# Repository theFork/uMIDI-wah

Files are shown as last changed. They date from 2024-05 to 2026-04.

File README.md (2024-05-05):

# uMIDI-wah

An optical guitar wah circuit based on the weeping demon circuit

* Uses [uMIDI](https://github.com/theFork/uMIDI) for control, MIDI and USB communication
* Optical wah control using a PWM

## uMIDI attachment
In order to be able to mount a uMIDI on top of the board, the three uMIDI GPIO connectors (boxed headers) have to be placed on its bottom side. Also, a male pin header row (1x10 pins, 2.54mm) has to be soldered to the MIDI and power section of the uMIDI module (also bottom side).

Another option would be to attach the uMIDI below the wah PCBA. In this case, the connectors have to side on the top side of the PCB.

In both cases, female headers are required for the wah PCBA:

* 3x Female header 2x5 pins, 2.54mm (i.e. TE 215307-5)
* 1x Female header 1x10 pins, 2.54mm (i.e. TE 1-215297-0)

## EDA
* Requires KiCad 8.x.x

## Ressources
Many of this is based on the work of Chet Gnegy: https://ccrma.stanford.edu/~chet/projects/weepingdemon.html

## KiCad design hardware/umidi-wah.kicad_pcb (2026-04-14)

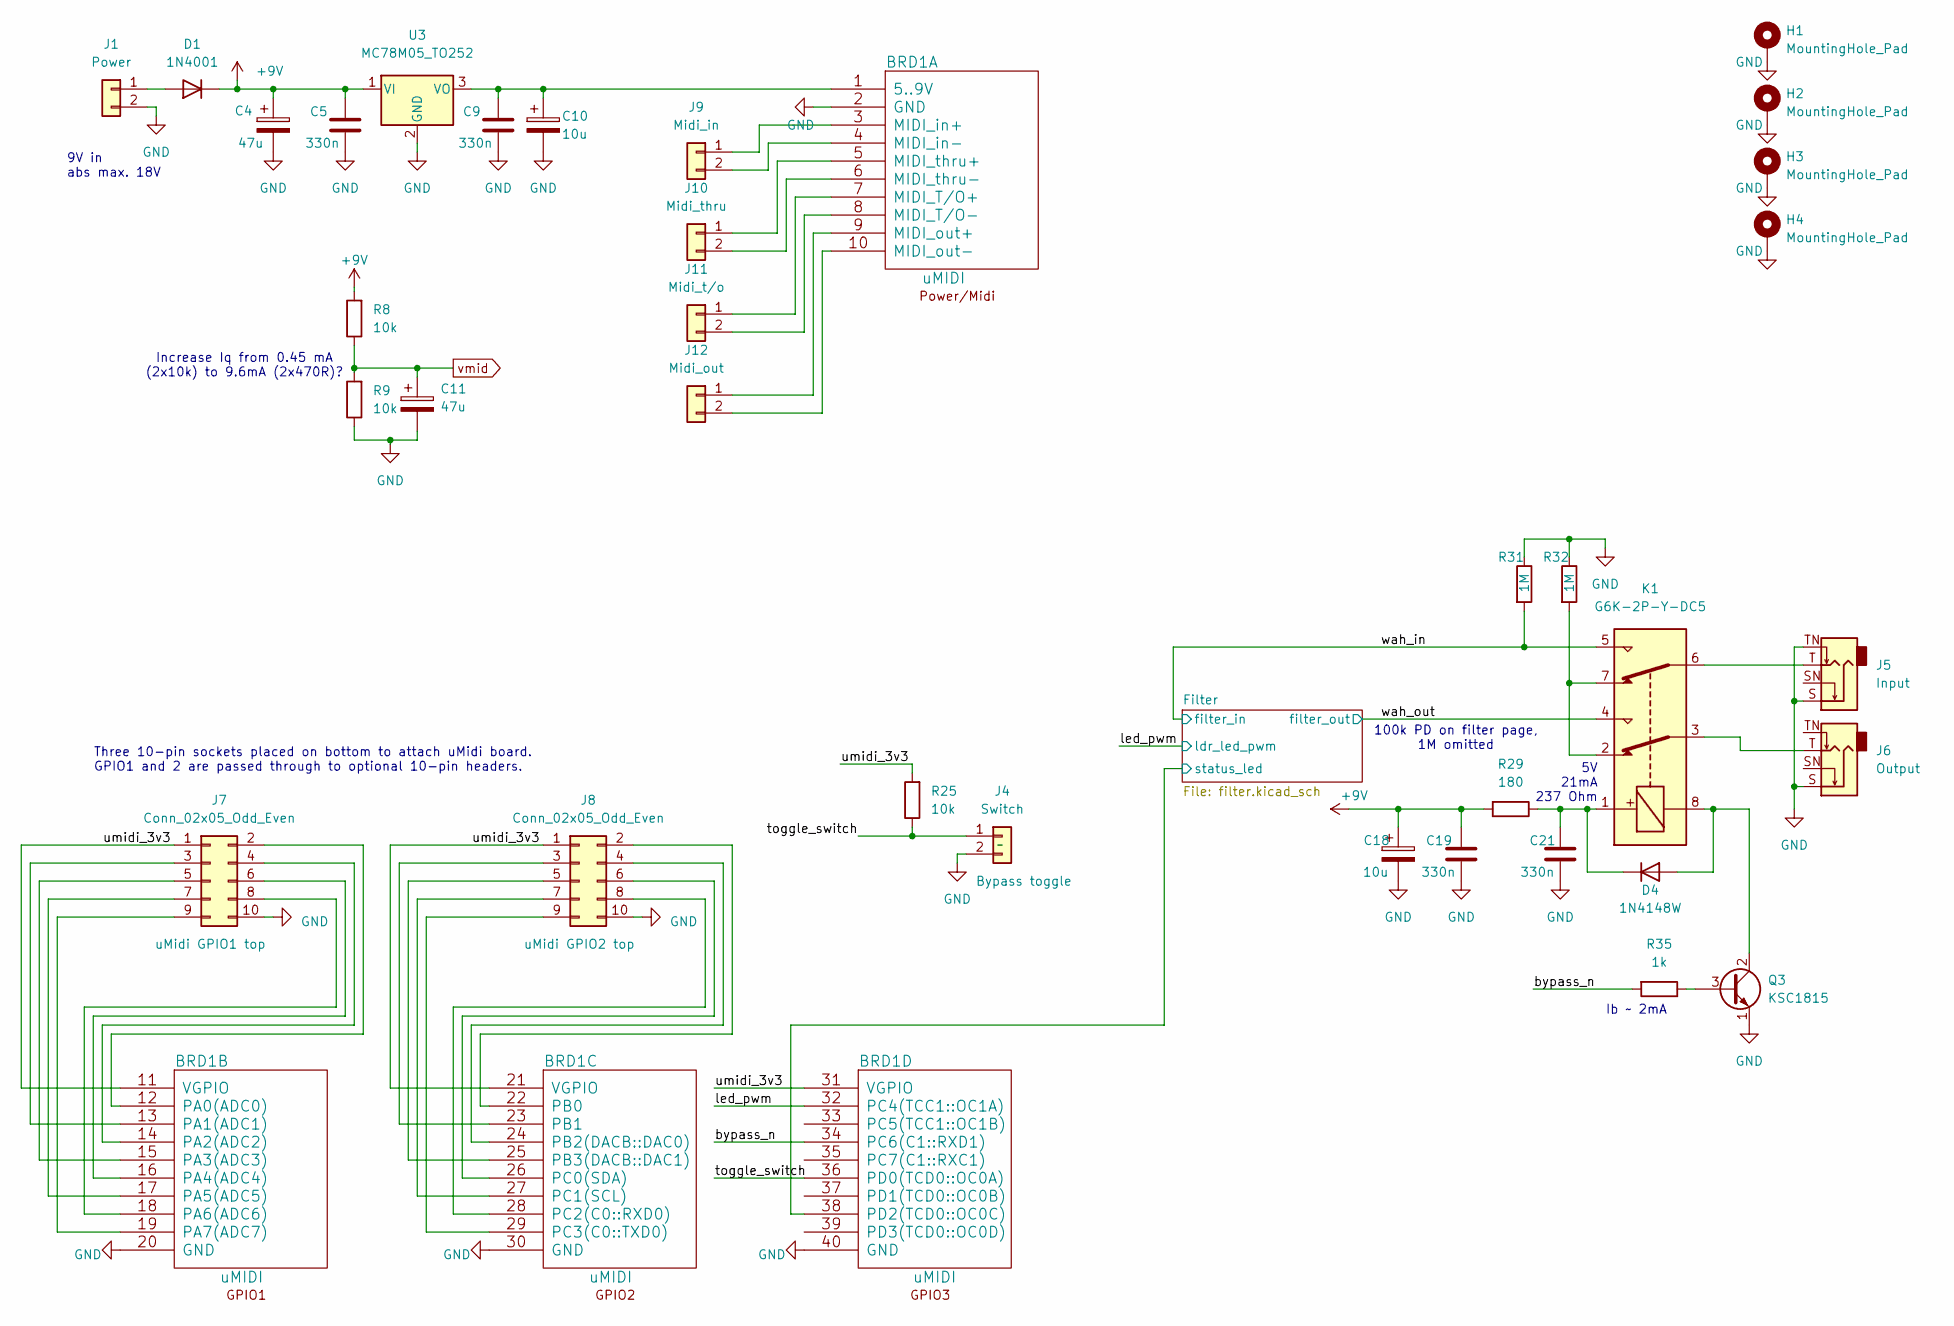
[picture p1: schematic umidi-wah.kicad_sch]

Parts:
BRD1: uMIDI; uMIDI_faceup
C4, C11: 47u; C_1206_3216Metric_Pad1.33x1.80mm_HandSolder
C5, C9, C19, C21: 330n; C_0805_2012Metric_Pad1.18x1.45mm_HandSolder
C10, C18: 10u; C_1206_3216Metric_Pad1.33x1.80mm_HandSolder
D1: 1N4001; D_DO-41_SOD81_P10.16mm_Horizontal
D4: 1N4148W; D_SOD-123
H1, H2, H3, H4: MountingHole_Pad; MountingHole_3.2mm_M3_Pad
J1: Power; SolderWire-1sqmm_1x02_P5.4mm_D1.4mm_OD2.7mm
J4: Switch; SolderWire-1sqmm_1x02_P5.4mm_D1.4mm_OD2.7mm
J5: Input; Jack_6.35mm_Neutrik_NMJ4HCD2_Horizontal
J6: Output; Jack_6.35mm_Neutrik_NMJ4HCD2_Horizontal
J7, J8: Conn_02x05_Odd_Even; IDC-Header_2x05_P2.54mm_Vertical
J9: Midi_in; SolderWire-1sqmm_1x02_P5.4mm_D1.4mm_OD2.7mm
J10: Midi_thru; SolderWire-1sqmm_1x02_P5.4mm_D1.4mm_OD2.7mm
J11: Midi_t/o; SolderWire-1sqmm_1x02_P5.4mm_D1.4mm_OD2.7mm
J12: Midi_out; SolderWire-1sqmm_1x02_P5.4mm_D1.4mm_OD2.7mm
K1: G6K-2P-Y-DC5; Relay_DPDT_Omron_G6K-2P-Y; Manufacturer Part Number G6K-2P-Y-DC5
Q3: KSC1815; TO-92; Manufacturer Part Number KSC1815
R8, R9, R25: 10k; R_0805_2012Metric_Pad1.20x1.40mm_HandSolder
R29: 180; R_0805_2012Metric_Pad1.20x1.40mm_HandSolder
R31, R32: 1M; R_0805_2012Metric_Pad1.20x1.40mm_HandSolder
R35: 1k; R_0805_2012Metric_Pad1.20x1.40mm_HandSolder
U3: MC78M05_TO252; TO-252-2; Manufacturer Part Number MC78M05CD

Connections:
+9V: C4.1, C5.1, C18.1, C19.1, D1.1 (K), R8.2, R29.2, U3.1 (VI); also elsewhere on the board
/Filter/status_led: BRD1.38 (PD2(TCD0::OC0C)); also elsewhere on the board
/bypass_n: BRD1.34 (PC6(C1::RXD1)), R35.2
/led_pwm: BRD1.32 (PC4(TCC1::OC1A)); also elsewhere on the board
/toggle_switch: BRD1.36 (PD0(TCD0::OC0A)), J4.1, R25.1
/umidi_3v3: BRD1.11 (VGPIO), BRD1.21 (VGPIO), BRD1.31 (VGPIO), J7.1, J8.1, R25.2
/wah_in: K1.5, R31.2; also elsewhere on the board
/wah_out: K1.4; also elsewhere on the board
GND: BRD1.2 (GND), BRD1.20 (GND), BRD1.30 (GND), BRD1.40 (GND), C4.2, C5.2, C9.2, C10.2, C11.2, C18.2, C19.2, C21.2, H1.1, H2.1, H3.1, H4.1, J1.2, J4.2, J5.S, J5.TN, J6.S, J7.10, J8.10, Q3.1 (E), R9.1, R31.1, R32.1, U3.2 (GND); also elsewhere on the board
unnamed: BRD1.1 (5..9V), C9.1, C10.1, U3.3 (VO)
unnamed: BRD1.7 (MIDI_T/O+), J11.1
unnamed: BRD1.8 (MIDI_T/O-), J11.2
unnamed: BRD1.3 (MIDI_in+), J9.1
unnamed: BRD1.4 (MIDI_in-), J9.2
unnamed: BRD1.9 (MIDI_out+), J12.1
unnamed: BRD1.10 (MIDI_out-), J12.2
unnamed: BRD1.5 (MIDI_thru+), J10.1
unnamed: BRD1.6 (MIDI_thru-), J10.2
unnamed: BRD1.12 (PA0(ADC0)), J7.2
unnamed: BRD1.13 (PA1(ADC1)), J7.3
unnamed: BRD1.14 (PA2(ADC2)), J7.4
unnamed: BRD1.15 (PA3(ADC3)), J7.5
unnamed: BRD1.16 (PA4(ADC4)), J7.6
unnamed: BRD1.17 (PA5(ADC5)), J7.7
unnamed: BRD1.18 (PA6(ADC6)), J7.8
unnamed: BRD1.19 (PA7(ADC7)), J7.9
unnamed: BRD1.22 (PB0), J8.2
unnamed: BRD1.23 (PB1), J8.3
unnamed: BRD1.24 (PB2(DACB::DAC0)), J8.4
unnamed: BRD1.25 (PB3(DACB::DAC1)), J8.5
unnamed: BRD1.26 (PC0(SDA)), J8.6
unnamed: BRD1.27 (PC1(SCL)), J8.7
unnamed: BRD1.28 (PC2(C0::RXD0)), J8.8
unnamed: BRD1.29 (PC3(C0::TXD0)), J8.9
unnamed: D1.2 (A), J1.1
unnamed: D4.2 (A), K1.8, Q3.2 (C)
unnamed: C21.1, D4.1 (K), K1.1, R29.1
unnamed: J5.T, K1.6
unnamed: J6.T, K1.3
unnamed: K1.2, K1.7, R32.2
unnamed: Q3.3 (B), R35.1
vmid: C11.1, R8.1, R9.2; also elsewhere on the board

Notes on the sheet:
Increase Iq from 0.45 mA (2x10k) to 9.6mA (2x470R)?
9V in abs max. 18V
Ib ~ 2mA
Three 10-pin sockets placed on bottom to attach uMidi board. GPIO1 and 2 are passed through to optional 10-pin headers.
100k PD on filter page, 1M omitted
5V 21mA 237 Ohm

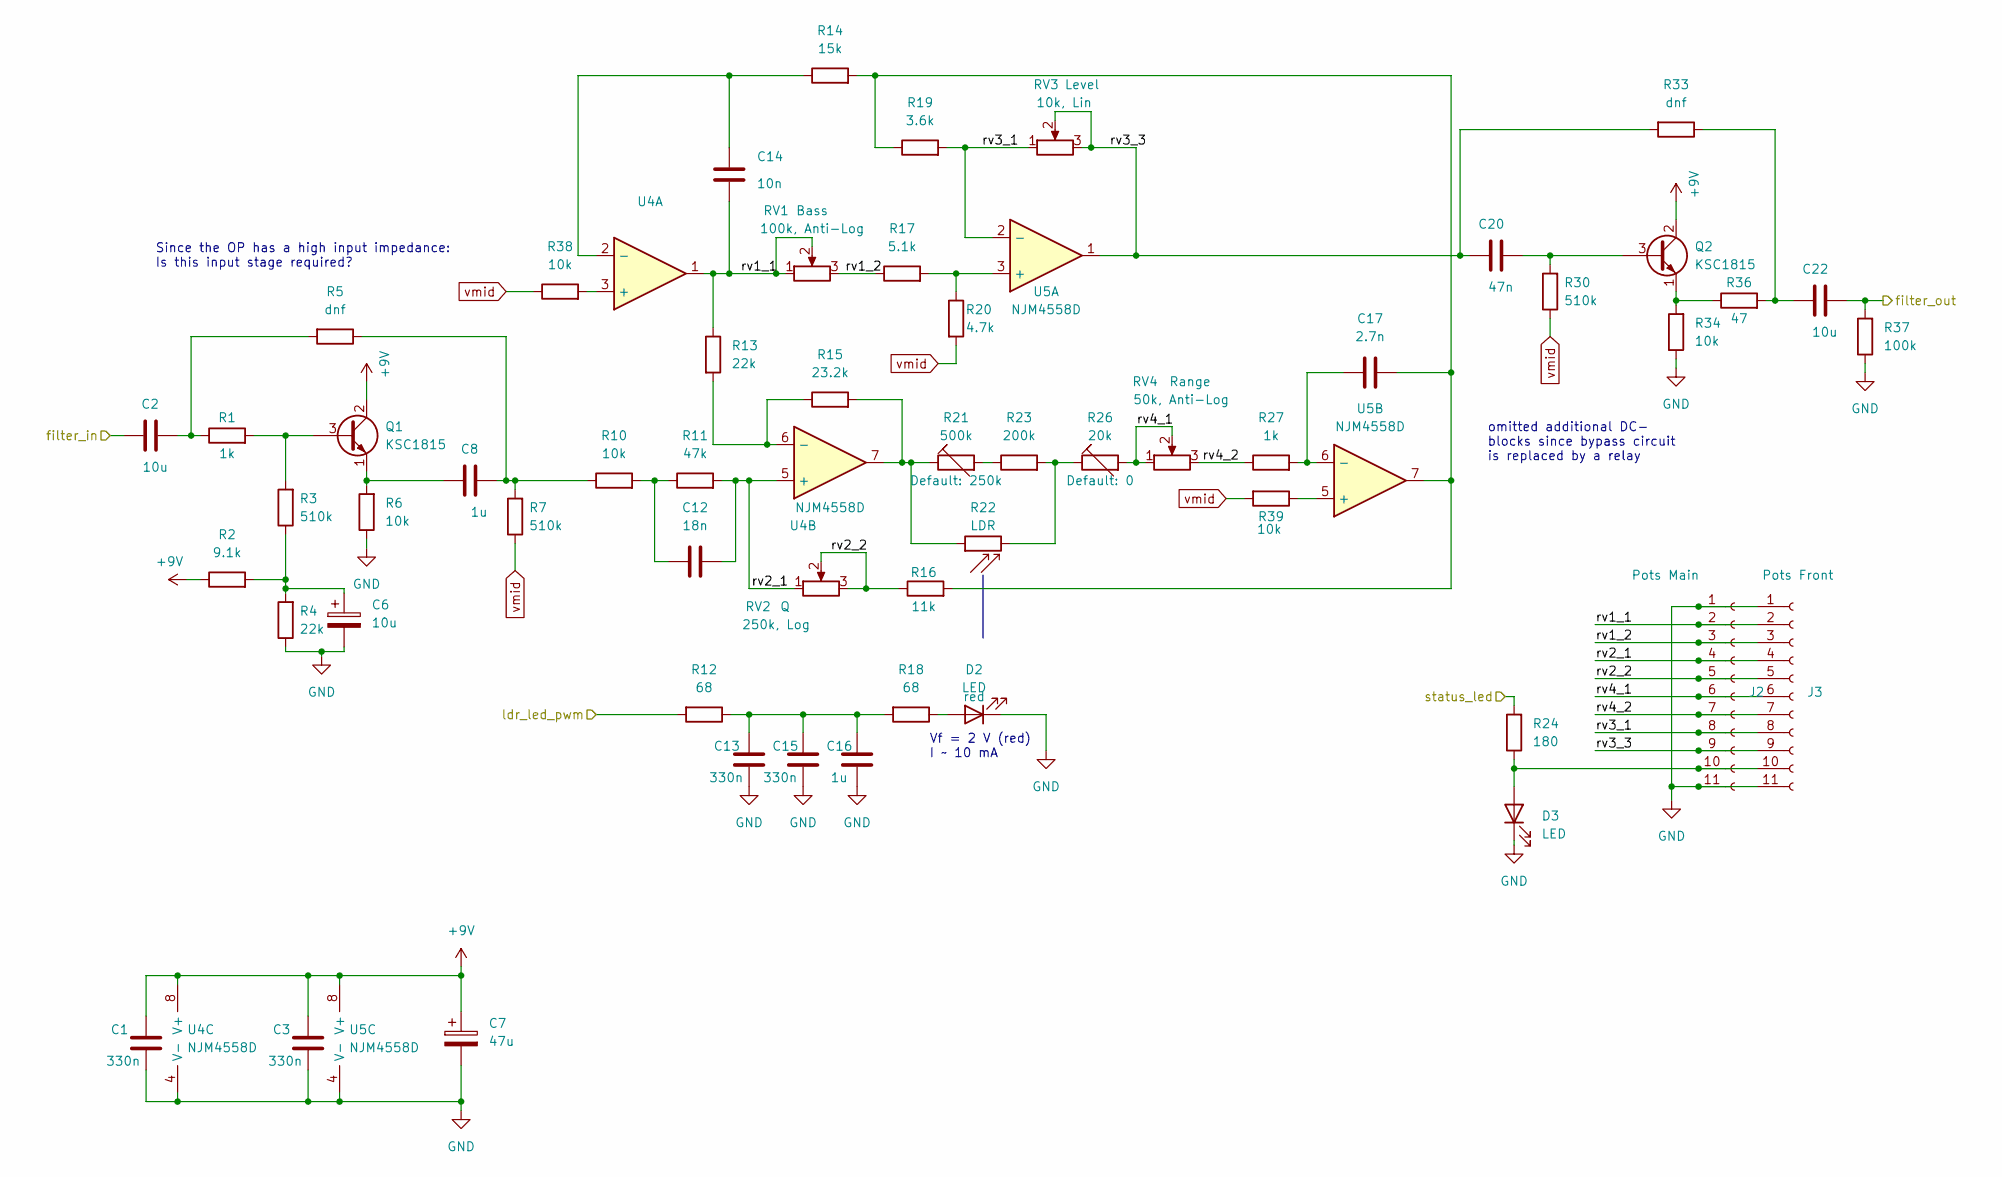
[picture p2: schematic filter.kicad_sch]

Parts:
C1, C3, C13, C15: 330n; C_0805_2012Metric_Pad1.18x1.45mm_HandSolder
C2, C22: 10u; C_Rect_L7.2mm_W11.0mm_P5.00mm_FKS2_FKP2_MKS2_MKP2
C6: 10u; C_1206_3216Metric_Pad1.33x1.80mm_HandSolder
C7: 47u; C_1206_3216Metric_Pad1.33x1.80mm_HandSolder
C8: 1u; C_Rect_L4.6mm_W5.5mm_P2.50mm_MKS02_FKP02
C12: 18n; C_Rect_L7.0mm_W2.5mm_P5.00mm
C14: 10n; C_Rect_L4.6mm_W5.5mm_P2.50mm_MKS02_FKP02; Manufacturer Part Number MKS0C021000B00JSSD
C16: 1u; C_0805_2012Metric_Pad1.18x1.45mm_HandSolder
C17: 2.7n; C_Rect_L7.0mm_W2.5mm_P5.00mm
C20: 47n; C_Rect_L4.6mm_W5.5mm_P2.50mm_MKS02_FKP02; Manufacturer Part Number MKS0C024700B00JSSD
D2, D3: LED; LED_D5.0mm
J2: Pots Main; PinHeader_1x11_P2.54mm_Vertical
J3: Pots Front; PinHeader_1x11_P2.54mm_Vertical
Q1, Q2: KSC1815; TO-92; Manufacturer Part Number KSC1815
R1, R27: 1k; R_0805_2012Metric_Pad1.20x1.40mm_HandSolder
R2: 9.1k; R_0805_2012Metric_Pad1.20x1.40mm_HandSolder
R3, R7, R30: 510k; R_0805_2012Metric_Pad1.20x1.40mm_HandSolder
R4, R13: 22k; R_0805_2012Metric_Pad1.20x1.40mm_HandSolder
R5, R33: dnf; R_0805_2012Metric_Pad1.20x1.40mm_HandSolder
R6, R10, R34, R38, R39: 10k; R_0805_2012Metric_Pad1.20x1.40mm_HandSolder
R11: 47k; R_0805_2012Metric_Pad1.20x1.40mm_HandSolder
R12, R18: 68; R_0805_2012Metric_Pad1.20x1.40mm_HandSolder
R14: 15k; R_0805_2012Metric_Pad1.20x1.40mm_HandSolder
R15: 23.2k; R_0805_2012Metric_Pad1.20x1.40mm_HandSolder
R16: 11k; R_0805_2012Metric_Pad1.20x1.40mm_HandSolder
R17: 5.1k; R_0805_2012Metric_Pad1.20x1.40mm_HandSolder
R19: 3.6k; R_0805_2012Metric_Pad1.20x1.40mm_HandSolder
R20: 4.7k; R_0805_2012Metric_Pad1.20x1.40mm_HandSolder
R21: 500k; Potentiometer_Piher_PT-10-V10_Vertical_Hole; Manufacturer Part Number PT10LV10-504A2020
R22: LDR; R_LDR_4.9x4.2mm_P2.54mm_Vertical; Manufacturer Part Number PDV P9004 or PDV 9203
R23: 200k; R_0805_2012Metric_Pad1.20x1.40mm_HandSolder
R24: 180; R_0805_2012Metric_Pad1.20x1.40mm_HandSolder
R26: 20k; Potentiometer_Piher_PT-10-V10_Vertical_Hole; Manufacturer Part Number PT10LV10-203A2020
R36: 47; R_0805_2012Metric_Pad1.20x1.40mm_HandSolder
R37: 100k; R_0805_2012Metric_Pad1.20x1.40mm_HandSolder
RV1: 100k, Anti-Log; Potentiometer_Alpha_RV16AF-20-15k-Single_Horizontal; Manufacturer Part Number RV16AF-20-15K-C100K
RV2: 250k, Log; Potentiometer_Alpha_RV16AF-20-15k-Single_Horizontal; Manufacturer Part Number RV16AF-20-15K-A250K
RV3: 10k, Lin; Potentiometer_Alpha_RV16AF-20-15k-Single_Horizontal; Manufacturer Part Number RV16AF-20-15K-B10K
RV4: 50k, Anti-Log; Potentiometer_Alpha_RV16AF-20-15k-Single_Horizontal; Manufacturer Part Number RV16AF-20-15K-C50K
U4, U5: NJM4558D; DIP-8_W7.62mm_Socket_LongPads; Manufacturer Part Number NJM4558D

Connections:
+9V: C1.1, C3.1, C7.1, Q1.2 (C), Q2.2 (C), R2.1, U4.8 (V+), U5.8 (V+); also elsewhere on the board
/Filter/rv1_1: C14.2, J2.2, J3.2, R13.1, RV1.1, RV1.2, U4.1
/Filter/rv1_2: J2.3, J3.3, R17.1, RV1.3
/Filter/rv2_1: C12.2, J2.4, J3.4, R11.2, RV2.1, U4.5 (+)
/Filter/rv2_2: J2.5, J3.5, R16.1, RV2.2, RV2.3
/Filter/rv3_1: J2.8, J3.8, R19.2, RV3.1, U5.2 (-)
/Filter/rv3_3: C20.1, J2.9, J3.9, R33.2, RV3.2, RV3.3, U5.1
/Filter/rv4_1: J2.6, J3.6, R26.2, RV4.1, RV4.2
/Filter/rv4_2: J2.7, J3.7, R27.1, RV4.3
/Filter/status_led: R24.2; also elsewhere on the board
/led_pwm: R12.2; also elsewhere on the board
/wah_in: C2.1; also elsewhere on the board
/wah_out: C22.2, R37.2; also elsewhere on the board
GND: C1.2, C3.2, C6.2, C7.2, C13.2, C15.2, C16.2, D2.1 (K), D3.1 (K), J2.1, J2.11, J3.1, J3.11, R4.1, R6.1, R34.1, R37.1, U4.4 (V-), U5.4 (V-); also elsewhere on the board
unnamed: C2.2, R1.1, R5.2
unnamed: C6.1, R2.2, R3.1, R4.2
unnamed: C8.2, R5.1, R7.2, R10.1
unnamed: C12.1, R10.2, R11.1
unnamed: C13.1, C15.1, C16.1, R12.1, R18.2
unnamed: C17.2, R14.2, R16.2, R19.1, U5.7
unnamed: C22.1, R33.1, R36.2
unnamed: D2.2 (A), R18.1
unnamed: D3.2 (A), J2.10, J3.10, R24.1
unnamed: Q1.3 (B), R1.2, R3.2
unnamed: C8.1, Q1.1 (E), R6.2
unnamed: C20.2, Q2.3 (B), R30.2
unnamed: Q2.1 (E), R34.2, R36.1
unnamed: R15.2, R21.1, R22.1, U4.7
unnamed: R21.2, R23.1
unnamed: R22.2, R23.2, R26.1
unnamed: R38.2, U4.3 (+)
unnamed: C14.1, R14.1, U4.2 (-)
unnamed: R13.2, R15.1, U4.6 (-)
unnamed: R17.2, R20.1, U5.3 (+)
unnamed: R39.1, U5.5 (+)
unnamed: C17.1, R27.2, U5.6 (-)
vmid: R7.1, R20.2, R30.1, R38.1, R39.2; also elsewhere on the board

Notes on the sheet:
omitted additional DC- blocks since bypass circuit is replaced by a relay
Vf = 2 V (red) I ~ 10 mA
Since the OP has a high input impedance: Is this input stage required?

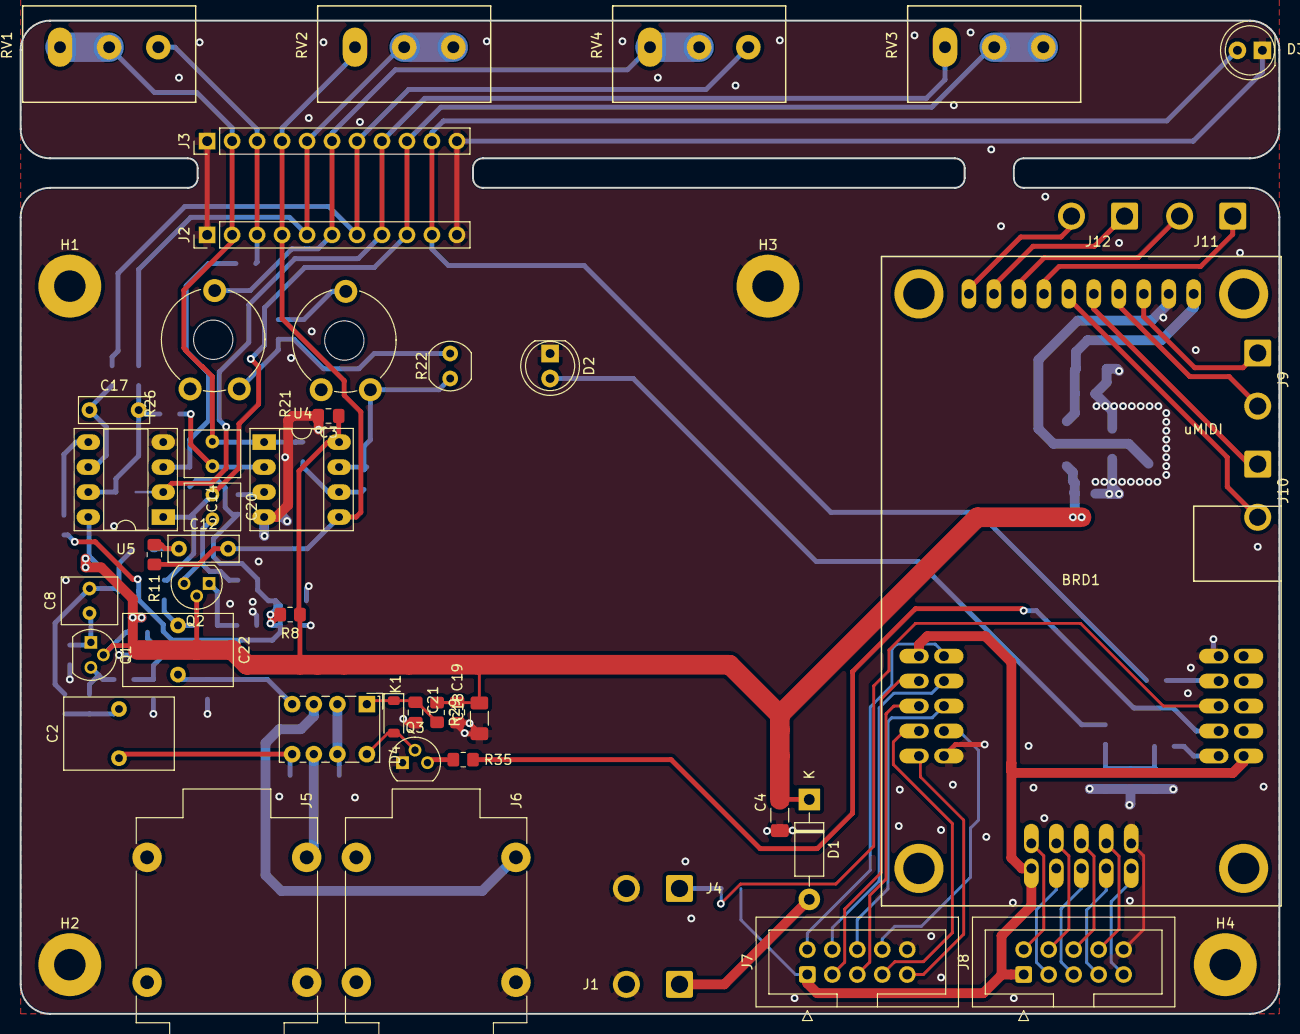
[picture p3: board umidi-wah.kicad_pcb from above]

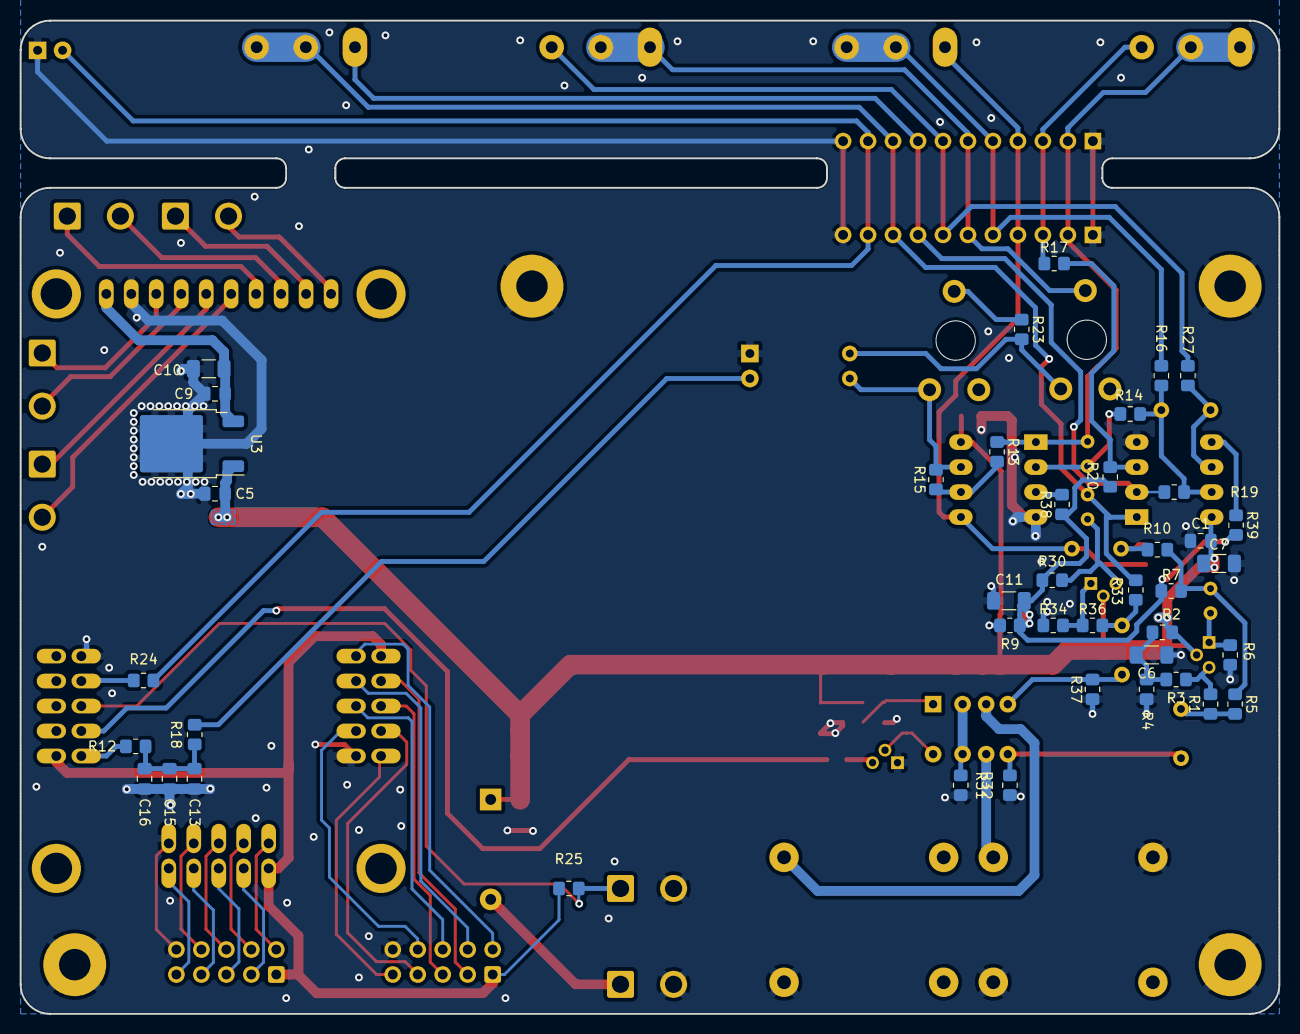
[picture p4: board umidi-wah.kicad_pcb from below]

Board: 2 copper layers, 128.0 x 101.0 mm, 92 parts (42 on the bottom side), 72 nets.

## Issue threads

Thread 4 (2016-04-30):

Second source LDR

theFork, 2016-04-30:
LDR is currently not available. Measure properties and find a replacement part.

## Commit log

2015-10-26 Remove rescue lib dependency; Join gnd and gnda
    [bypass.sch, uMIDI-wah.sch, wah.sch]
2015-10-26 Select trimmer and footprint
    [uMIDI-wah.sch]
2015-10-26 Fix relay footprint
    [uMIDI-wah.sch]
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2015-10-26 Start placement and routing
    [uMIDI-wah.kicad_pcb]
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2015-11-01 Fix RV1 bom fields
    [uMIDI-wah.sch]
2015-11-01 Add capacitor bom fields
    [uMIDI-wah.sch]
2015-11-01 Add ldr bom fields; Change footprint
    [uMIDI-wah.sch]
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2015-11-01 Add resistor bom fields
    [uMIDI-wah.sch]
2015-11-02 Add filter circuit to the pwm led
    [bypass.sch, uMIDI-wah.kicad_pcb, uMIDI-wah.sch]
2015-11-09 Replace opamp uA741 by TL071
    [uMIDI-wah.kicad_pcb, uMIDI-wah.sch]
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2015-12-04 Increase pad size of ribbon connector
    [uMIDI-wah.kicad_pcb]
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2015-12-05 Fix SOIC package width
    [uMIDI-wah.kicad_pcb]
2016-01-23 Fix 470k resistor supplier link
    [uMIDI-wah.sch]
2016-01-23 Fix C9 supplier link
    [uMIDI-wah.sch]
2016-01-23 Change C7 and C11; Adapt supplier links
    [uMIDI-wah.sch]
2016-01-23 Constrain volume pot range
    [bypass.sch, uMIDI-wah.sch]
2016-01-23 Increase pcb size; Add label
    [bypass.sch, uMIDI-wah.kicad_pcb, uMIDI-wah.sch]
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2016-01-30 Add 9V polarity protection diode
    [uMIDI-wah.kicad_pcb, uMIDI-wah.sch]
2016-02-21 Increase LDR pad size
    [uMIDI-wah.kicad_pcb]
2019-03-17 Add QUCS simulation of v1.0 wah circuit
    [wah.sch]
2019-03-17 Import wah schematic from simulation into KiCad
    [uMIDI-wah.kicad_pcb, uMIDI-wah.sch]
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2019-05-04 Edit eval schematic; Import bypass
    [bypass.sch, led-driver.sch, uMIDI-wah.sch]
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2019-05-04 Use 0805 footprint for all resistors
    [bypass.sch, led-driver.sch, uMIDI-wah.sch]
2019-05-04 Use 0805 footprint for all capacitors
    [bypass.sch, led-driver.sch, uMIDI-wah.sch]
2019-05-09 Add seconde fasel and Vref circuit
    [bypass.sch, led-driver.sch, uMIDI-wah.sch]
2019-05-09 Select and set all pots to 470k
    [uMIDI-wah.sch]
2019-05-09 Add footprints and part info for IC and inductors
    [led-driver.sch, uMIDI-wah.sch]
2019-05-11 Create footprint for audio jacks
    [led-driver.sch, uMIDI-wah.sch]
2019-05-11 Create footprint for LDRs
    [uMIDI-wah.sch]
2019-05-11 Select and update LED circuit
    [led-driver.sch]
2019-05-11 Assign footprints; add led supply circuit
    [led-driver.sch, uMIDI-wah.sch]
2019-05-18 Fix footprints
    [bypass.sch, led-driver.sch, uMIDI-wah.sch]
2019-05-18 Initial placement and bom optimization
    [bypass.sch, led-driver.sch, uMIDI-wah.kicad_pcb]
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2019-05-21 Use second relay to switch between inductors
    [bypass.sch, inductor.sch, led-driver.sch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]
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2020-03-08 Optimize place & route, add label and OSHW logo
    [uMIDI-wah.kicad_pcb]
2020-03-15 Add missing manufacturer links
    [bypass.sch, inductor.sch, led-driver.sch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]
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2020-03-26 Revision BOM: Get low-tech parts from Reichelt
    [bypass.sch, inductor.sch, led-driver.sch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]
2020-05-16 Fix relais supply
    [bypass.sch, inductor.sch, led-driver.sch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]
2020-05-16 Add in-/output labels to audio jacks
    [uMIDI-wah.kicad_pcb]
2023-02-18 Wipe all kicad files
    [bypass.sch, inductor.sch, led-driver.sch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]
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2023-02-18 Add in/out buffers, loosely based on demon circuit
    Keeping in mind that we will use a relay true bypass. Thus, we omitted the jfets and some dc blocks.
    [umidi-wah.kicad_sch]
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2023-02-18 Add led and filter circuit
    [umidi-wah.kicad_sch]
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2023-02-19 Add power input and 5v ldo for umidi supply
    [umidi-wah.kicad_sch]
2023-02-19 Add buffer stage bypass resistors
    Can be assembled to bypass input or output buffer stages.
    [umidi-wah.kicad_sch]
2023-02-19 Use gpio pinout from current uMidi wah app
    [umidi-wah.kicad_sch]
2023-02-19 Add status led and toggle switch connector
    [umidi-wah.kicad_sch]
2023-02-19 Convert led filter to T-type
    Use the same values for the caps as used in our prototype. Use 2x 68 ohms instead of 2x 100 ohms, since this still results in a quiet low led current (10mA)
    [umidi-wah.kicad_sch]
2023-02-19 Add/show potentiometer function fields
    [umidi-wah.kicad_sch]
2023-02-20 Annotate schematic, assign footprints for jacks
    [umidi-wah.kicad_sch]
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2023-03-03 Use trim resistors for ldr tuning
    [umidi-wah.kicad_sch]
2023-03-03 Define trimmer and ldr footprints; Add supply infos
    [umidi-wah.kicad_sch]
2023-03-03 Add all uMidi pin sockets for mech stability
    [umidi-wah.kicad_sch]
2023-03-06 Move filter circuit to designated sheet
    [filter.kicad_sch, umidi-wah.kicad_sch]
2023-03-16 Add top pin headers
    [umidi-wah.kicad_sch]
2023-03-16 Fix Opamps
    [filter.kicad_sch, umidi-wah.kicad_sch]
2023-03-16 Add wire connectors for front panel with pots
    [filter.kicad_sch]
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2023-03-16 Add pcb outline and test milling layer
    [umidi-wah.kicad_pcb, umidi-wah.kicad_sch]
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2023-03-18 Connect power to uMidi module
    [umidi-wah.kicad_sch]
2023-03-18 Add header description to umidi symbol; Update schematic
    [filter.kicad_sch, umidi-wah.kicad_sch]
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2023-03-18 Swap pots in schematic (now including mounting pins)
    [filter.kicad_sch]
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2023-03-22 Fix range poti value; Fix poti directions; Specify taper types
    [filter.kicad_sch]
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2023-03-23 Replace bourns potentiometers in schematic and board
    [filter.kicad_sch, umidi-wah.kicad_pcb]
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2023-03-23 Add supplier link; Change footprint of 18n film cap
    [filter.kicad_sch, umidi-wah.kicad_pcb]
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2023-03-23 Specify 2n7 foil cap; Use generic 2.5/5mm footprints
    [filter.kicad_sch, umidi-wah.kicad_pcb]
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2023-04-22 Fix uMIDI footprint (remove silkscreen)
    [umidi-wah.kicad_pcb]
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2024-04-30 Make C8 footprint more generic (2.5 or 5mm pin distance)
    [umidi-wah.kicad_pcb]
2024-05-03 Redesign 9V distribution
    [umidi-wah.kicad_pcb]
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2024-05-03 Add solder holes for midi signals
    Now, it is possible to make the entire umidi-pcba pluggable.
    [umidi-wah.kicad_pcb, umidi-wah.kicad_sch]
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2024-05-19 Rotate pwr connector (increase clearance to signal out)
    [umidi-wah.kicad_pcb]
2024-05-19 Replace gpio connectors by boxed headers
    [umidi-wah.kicad_pcb, umidi-wah.kicad_sch]
2024-05-19 Small tweaks -> DRC clean
    Fix typo in board name, move umidi slighty south
    [umidi-wah.kicad_pcb]
2024-06-18 Fix integrator positive input (is now vmid)
    [filter.kicad_sch, umidi-wah.kicad_pcb, umidi-wah.kicad_sch]
2024-06-18 Fix unintended filter_out signal union. Revise some placement.
    [filter.kicad_sch, umidi-wah.kicad_pcb, umidi-wah.kicad_sch]
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2024-07-04 Fix: Connect R20 low side to Vmid instead of GND
    [filter.kicad_sch, umidi-wah.kicad_pcb]
2026-02-26 WIP: Improve EMC. Move relais between in and output.
    [filter.kicad_sch, umidi-wah.kicad_pcb, umidi-wah.kicad_sch]
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2026-02-27 Move filter circuit to the left as far as possible
    [filter.kicad_sch, umidi-wah.kicad_pcb, umidi-wah.kicad_sch]
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2026-03-02 Route all missing airwires
    [umidi-wah.kicad_pcb]
2026-03-02 Fix drc issues
    [umidi-wah.kicad_pcb]
2026-03-02 Move primary midi i/o to right edge (increase distance)
    [umidi-wah.kicad_pcb]
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2026-04-14 Update to KiCAD 10; Set R15 from 23k to 23k2 (E96)
    [filter.kicad_sch, umidi-wah.kicad_pcb, umidi-wah.kicad_sch]
